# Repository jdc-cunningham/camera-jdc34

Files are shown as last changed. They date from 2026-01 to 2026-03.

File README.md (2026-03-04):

### JDC34 Camera

A custom camera body based on Raspberry Pi ecosystem

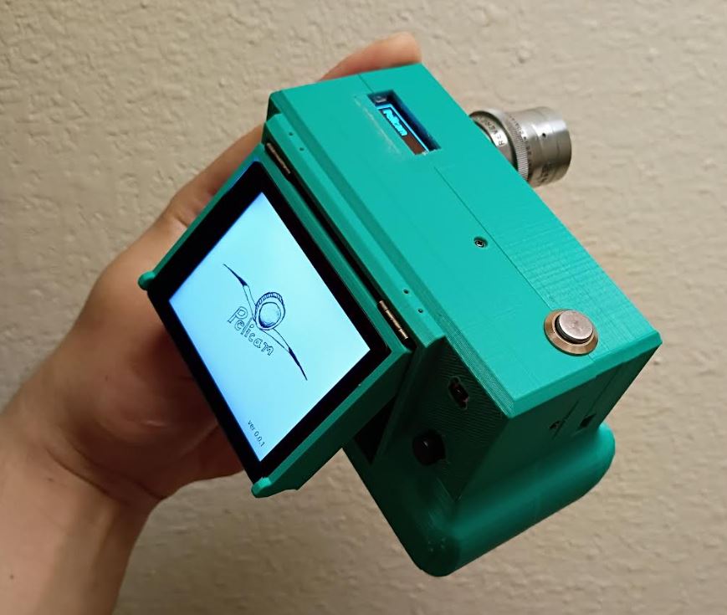
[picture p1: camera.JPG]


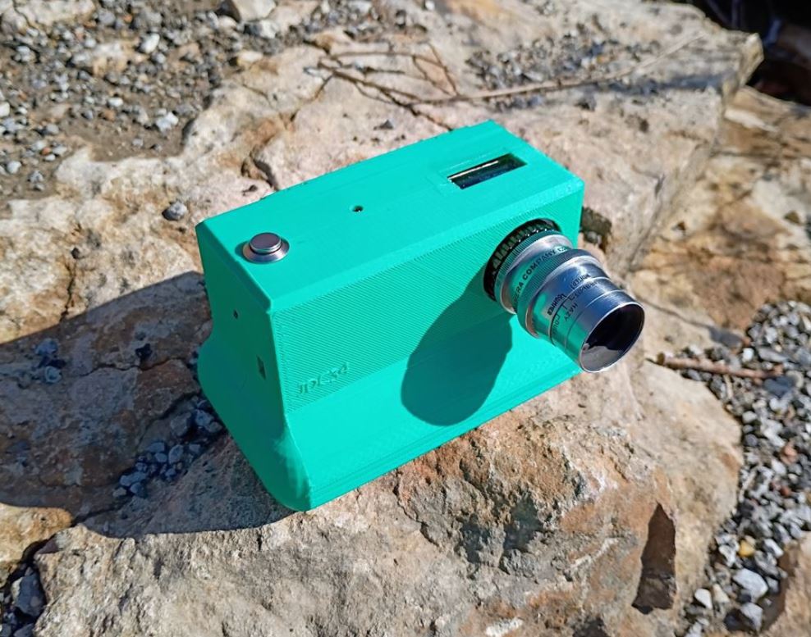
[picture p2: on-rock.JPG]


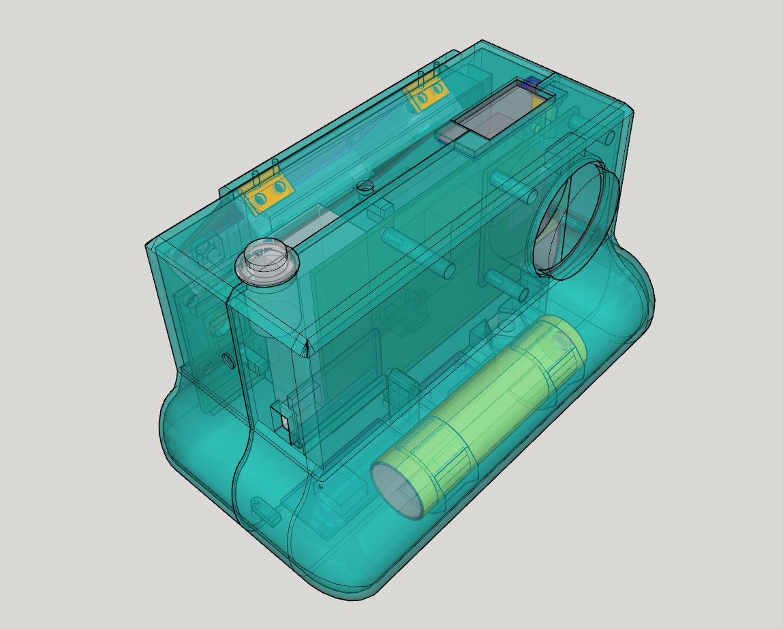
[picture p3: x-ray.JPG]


#### Features

- 2.8" 480x640 DSI waveshare touchscreen display
- 0.91" OLED
- 10-axis IMU
- 7 physical button interface
- full sized Raspberry Pi 4B
- powered by single 18650 cell

### Unit cost: $231.00

See the [parts list](./hardware/PARTS_LIST.md)

Note: you can reduce price in some areas eg. using a smaller SD card

Lens not included in cost

### Software

This uses [Pelicam](https://github.com/jdc-cunningham/pelicam) which is in development. The original software is [here](https://github.com/jdc-cunningham/modular-pi-cam/tree/master/cameras/pi-zero/large-display/software). But that was written for SPI displays.

### Media

For development videos and sample photos see my hardware YouTube channel [Vanta Wing](https://www.youtube.com/watch?v=lcudzqBnKbo&list=PL60azPuS5CZjkKGVGffiGK8XfBCXdif9R)

### About the name
The name is my name but also it's 3 c's (including the word camera) and the camera number. Yeah I do have other camera bodies I want to design and make. One would be based on the ESP32 ecosystem, means lower resolution but yeah.

I haven't thought of an actual name for this camera so... I figure I'd just use numbers.

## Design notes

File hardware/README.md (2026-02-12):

### Hardware

See the [parts list](./PARTS_LIST.md) for itemized breakdown of parts and cost.

#### Please note:

The tiny OLED on top eg. 0.91" OLED requires a 3A DC-DC boost converter to work (along with the rest of the system).

The cheap 2A DC-DC boost converter will not cut it (results in the 0.91" display being scrambled on boot).

Either don't use it, or use it and get a more expensive power supply like this one: (`$15` each vs. `$0.70` each eg. 2A)

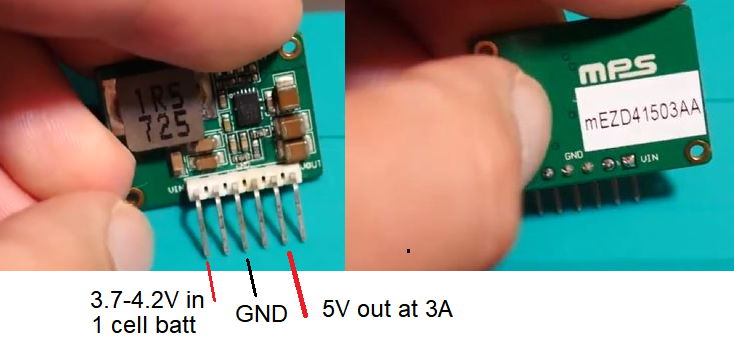
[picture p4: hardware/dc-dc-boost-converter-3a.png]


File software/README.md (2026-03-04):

### Software

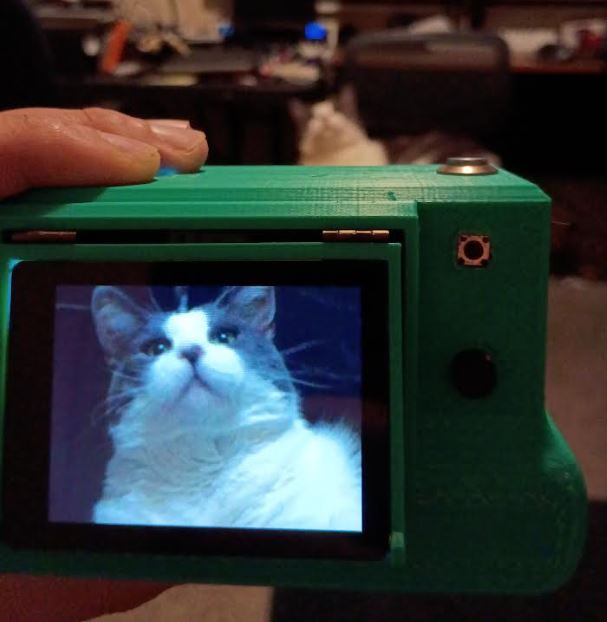
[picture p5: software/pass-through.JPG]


### Minimal software

See this [video](https://www.youtube.com/watch?v=SRtKM-NrlgQ) going over this code.

This code is crude, I put it together in a day so I could use this camera the following day.

Very basic camera software that features these abilities:

* button interfacing
* show live camera passthrough
* take a picture
* view the picture through list on touchscreen
* display text on OLED

#### Prerequisite

There is quite a bit of initial setup process on this [page](./fresh-os-install-steps.md).

I need to do that thoroughly/not in a rush.

After that you can do the following:

- Make a virtual env

In this software folder run `$python -m venv .jdc34-cam` then activate it

After that, run `$pip install -r requirements.txt`

- openbox

Do `$chmod +x` on openbox

- launch the window

`$sudo xinit ./openbox`

- running the menu on boot

I used systemd to do this. You can see this [page](./systemd.md) on setting up a systemd file.

### Pelicam

[Pelicam](https://github.com/jdc-cunningham/pelicam) is the full-featured software intended to drive different camera modules, display types and small or full-sized Raspberry Pis.

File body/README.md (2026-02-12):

### Disclaimer

Please note: I designed, printed and built this camera in 3 days.

The front shell needs some corrections, I'll remove this message once I have made the changes. In general this mesh is messed up, I did the modeling in SketchUp and it has problems with solids. Refer to the design flaws file.

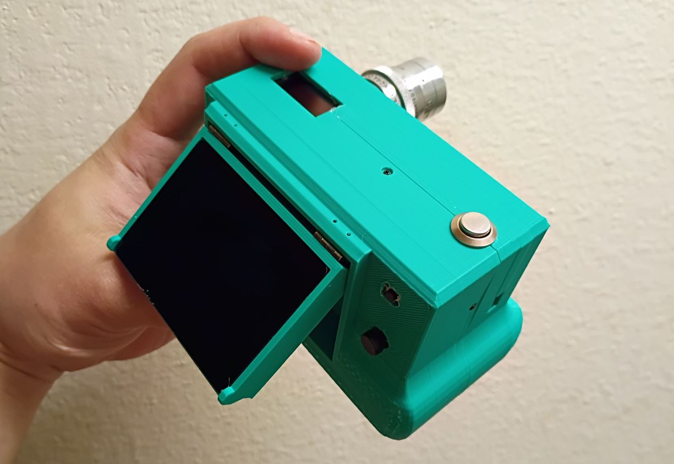
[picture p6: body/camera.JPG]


### Print times at 20% infill

- Display caddy - 2hrs
- Back shell - 11 hrs
- Front shell - 13.5 hrs

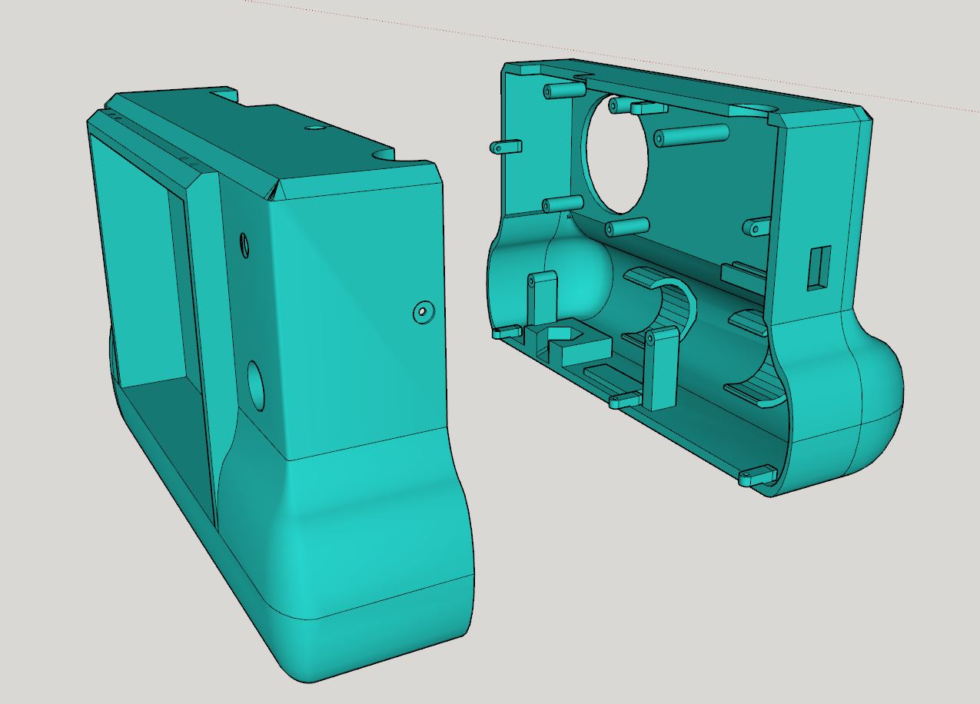
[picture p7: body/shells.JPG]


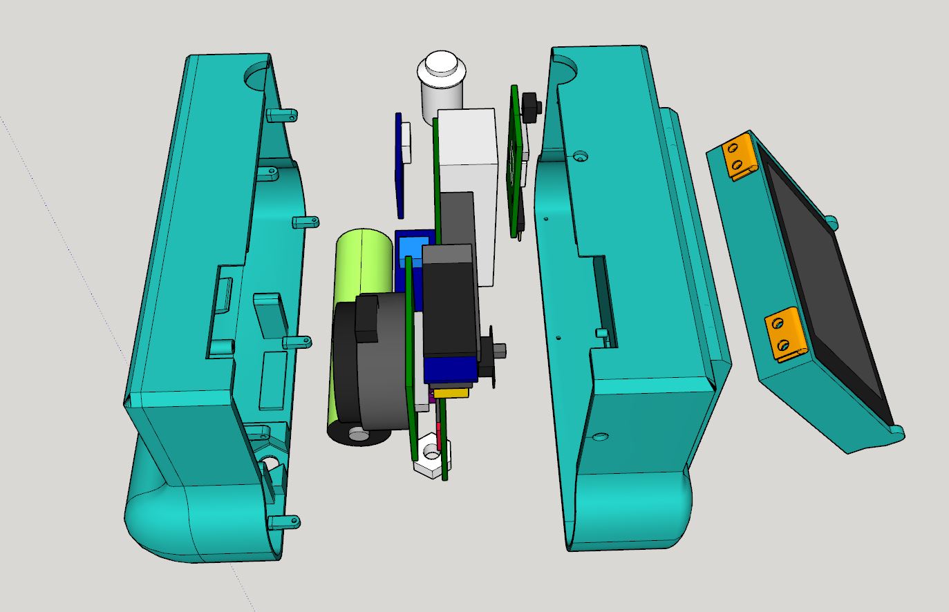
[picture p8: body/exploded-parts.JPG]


### Design flaws

I've written this on [another page](./design-flaws.md)

#### Note about the lens mount

I did not realize that the [flat plate](http://forums.raspberrypi.com/download/file.php?id=75978) part of the lens mount can be adjusted (flat screw) and then there is the CS adapter itself that can be moved. In this camera I designed the flat plate to be flush against the camera body. Ideally that would be able to rise below/above the front part of the camera, I need to adjust the design for that.

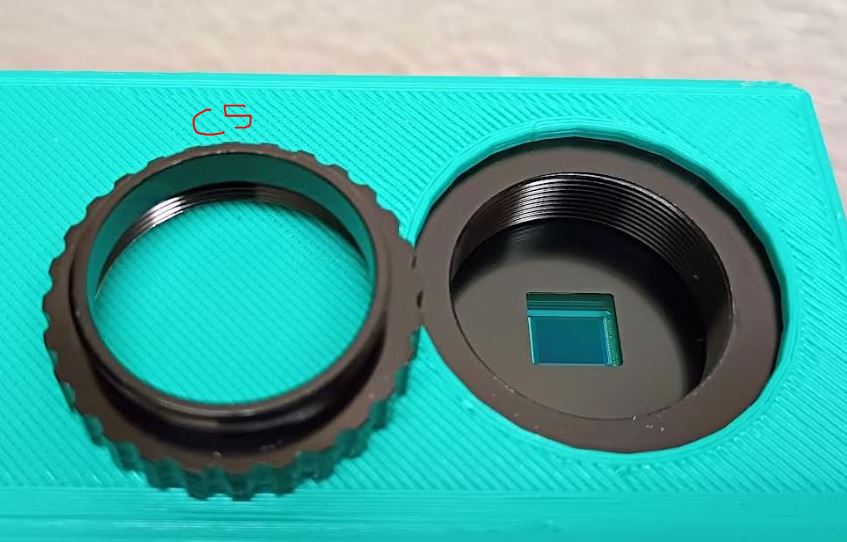
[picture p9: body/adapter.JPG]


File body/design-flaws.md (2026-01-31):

### General notes

The surface finish is from choice, if you print it the other way it takes a lot longer but you'll get a nice smooth finish vs. where support was detached.

The specific problems:

- HQ mount pegs are wrong, don't match, so I just hot-glued the HQ cam to the body which is not bad since you're going to attach
- the bottom-left mount for the RPi 4B is not actually attached when it prints which is weird
- the screw mounts that hold the two halves together are too small/frail, be careful, I snapped one of them on accident and had to print this A-shape thing to go around the broken screw mount
- the charger holder is bad, I need to make that be two ends and as L shape, no support in between that is hard to take out, the problem is the charger gets hot, hot enough to re-melt hot glue
- the back-button on the back shell, is not designed right, needs to be a square

While not intentional, it's tight to close the screen, since the hinge doesn't have any resistance, it just follows gravity. Currently the scringe hinge as is works well for pushing it in/keeping it closed.

I did fix the OLED cutout, it was too big for my taste, and I just printed a small wedge and superglued it on mine. But you can see if you print this as is you will get a usable body.

### External design flaws

- hinge gap and back button

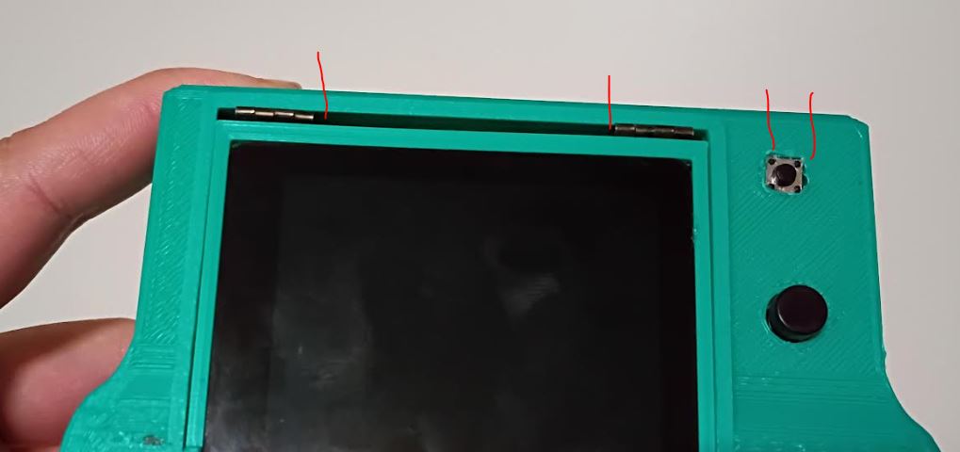
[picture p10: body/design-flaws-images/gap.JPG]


The back button I had designed the center black part to pop out just a little bit, while the outer part (tiny black dots) were underneath a thin piece of plastic, this was a mistake, as the smaller outer dots are almost are pretty tall... I ended up just having to take a soldering iron and roughly cutting out a square and hot-gluing it in place.

The hinges should have been pout out to the side more, I didn't realize how big of a gap that is in the middle, in that case you'd just drop the ceiling. The top of the LCD lid flips away so the ceiling can just be pulled straight down.

Although not shown here, the bottom of the display presses tightly into the body through compression not by design, it was lucky.

I would also put fixed/rotated slats/angles so the display can open at certain angles and not flop around like it does now based on gravity.

- OLED hole is too big (fixed in 3D model)

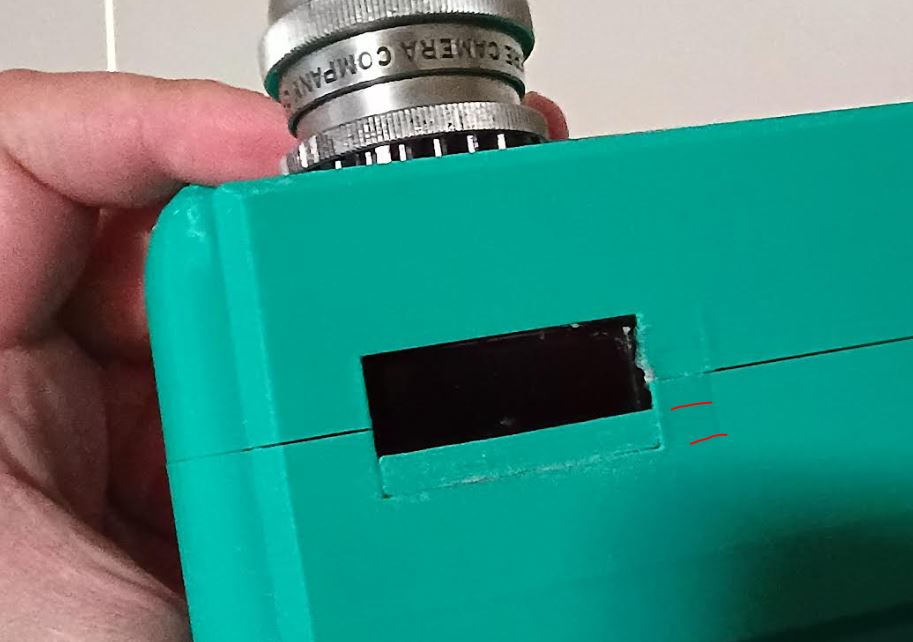
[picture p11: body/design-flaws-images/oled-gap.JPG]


You can see in red the size of the gap. The Pi 4B actually runs pretty warm so when I filled that in, I added a ramp shape so it can still let air out, since there aren't any directly-designed air flow holes.

### Internal design flaws

- charging board

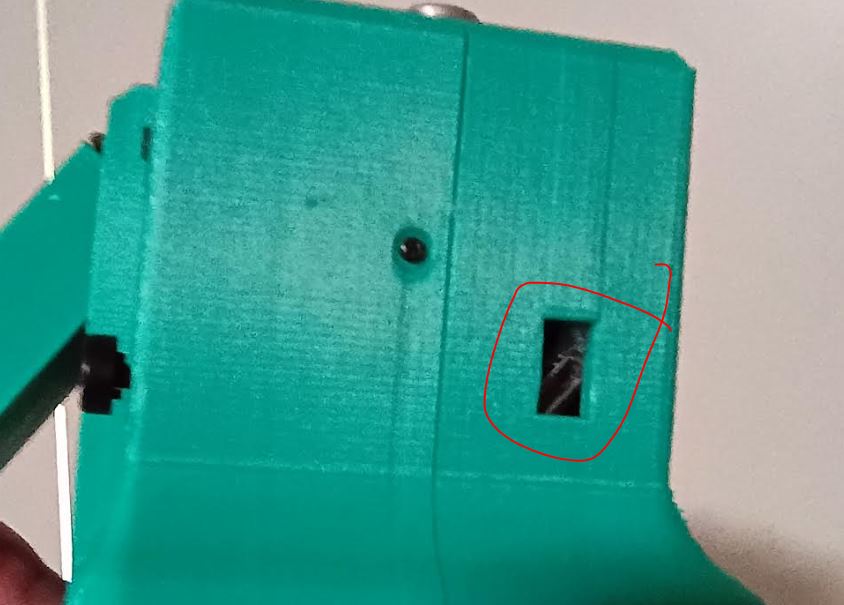
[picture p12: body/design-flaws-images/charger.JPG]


This is an external video but you can see the result I have. The problem is this board gets hot while the battery charges. So it will unmelt hotglue. I didn't design a good support for it internally.

- switch and screw holes

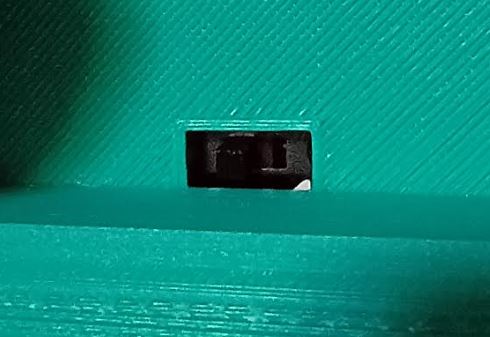
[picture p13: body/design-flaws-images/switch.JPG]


This is another external photo but inside, the screw mounts were too small, I ended up just hot-gluing the switch the body.

The other problem is it's not that easy to get access to the switch, I use the tip of my finger. I was aware of this while designing it but I was focused on making the switch hidden.

Not directly visible but side screw holes are also problematic. I have to make them thicker so they're not so easy to break.

No seam, because the shape is not normal and in some places thin, so I didn't design a seam. All the other cameras had a seam but they were simple rectangle edges.

- HQ cam screw mounts

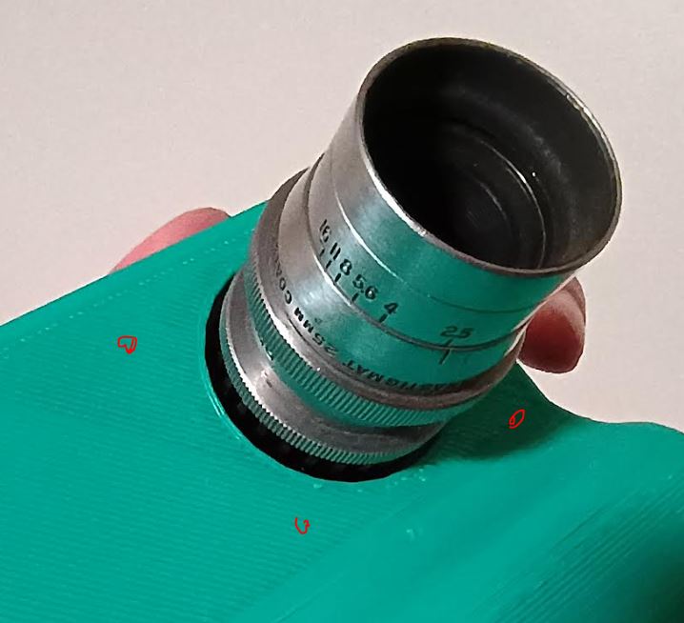
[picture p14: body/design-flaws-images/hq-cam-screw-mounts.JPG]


So I think what happened here is I used Arducam's IMX477 board measurements so the holes are off. If they do match then nvm but I believe I pulled a model I made around that board from the ML Hat Cam. Anyway the screw mounts didn't line up and I also ended up hot-gluing the sensor to the camera body. Which is not a bad thing considering how many random lenses/big lenses I attach to this camera.

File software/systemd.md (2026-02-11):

### Create a service

You can name the service whatever you want.

```
$sudo nano /etc/systemd/system/jdc34-cam.service
$sudo systemctl enable jdc34-cam.service
$sudo systemctl daemon-reload
$sudo systemctl restart jdc34-cam.service
```

#### jdc34-cam.service contents

```
[Unit]
Description=Start JDC34 Camera Software
After=multi-user.target

[Service]
Type=idle
WorkingDirectory=/home/pi/camera-jdc34/software
User=root
ExecStart=xinit ./openbox
Restart=always

[Install]
WantedBy=multi-user.target
```

Openbox will launch a window which will run main.py which runs OpenCV

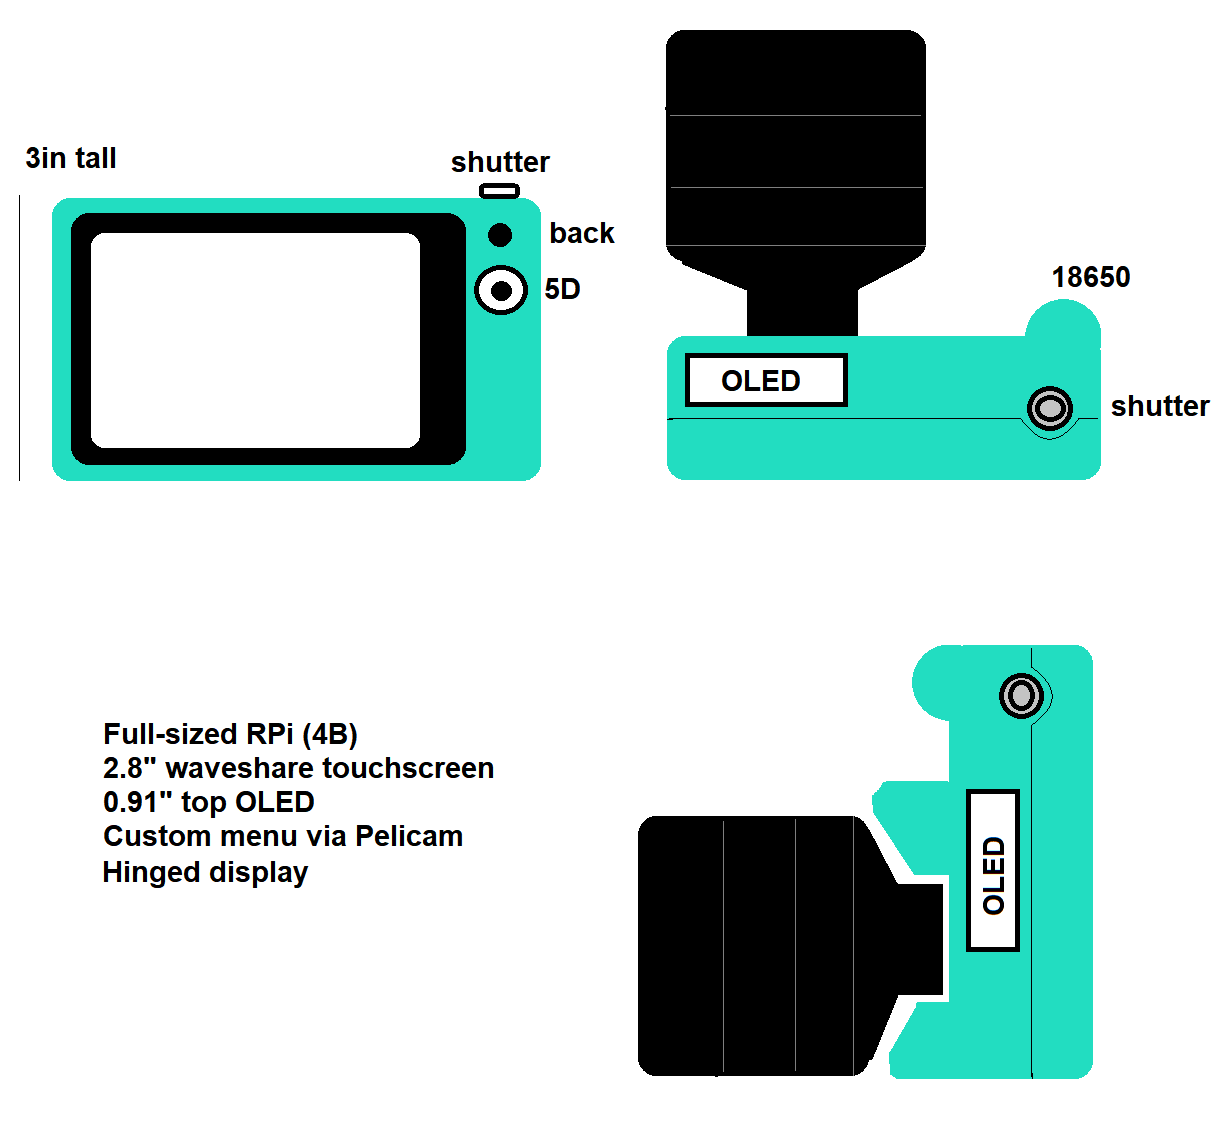
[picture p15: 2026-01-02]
init-design.png

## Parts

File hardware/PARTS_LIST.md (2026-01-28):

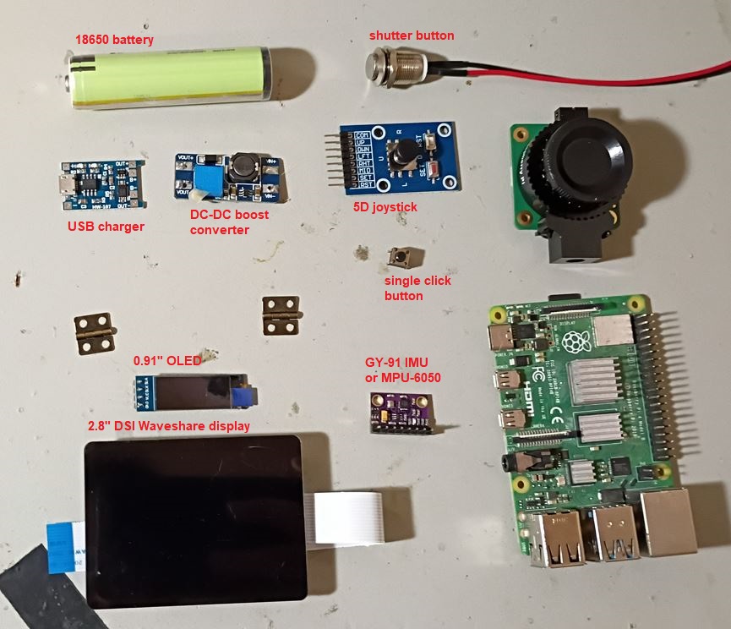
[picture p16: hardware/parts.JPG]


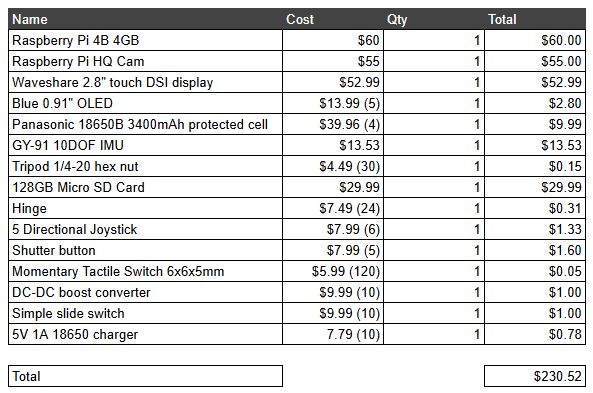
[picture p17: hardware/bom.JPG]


Amazon Affiliate Links

0.91" OLED https://amzn.to/49jh50v

2.8" Waveshare Touchscreen DSI Display https://amzn.to/49jh50v

DC-DC boost converter https://amzn.to/49jh50v

GY-91 10DOF IMU https://amzn.to/49jh50v

5D joystick https://amzn.to/3NcuRKW

1S BMS https://amzn.to/3NcuRKW

USB Li-Ion charger https://amzn.to/3NcuRKW

single button https://amzn.to/44TAjIT

shutter button https://amzn.to/44TAjIT

pack of assorted resistors https://amzn.to/453sS1S

Not pictured is a 10K resistor needed for the buttons

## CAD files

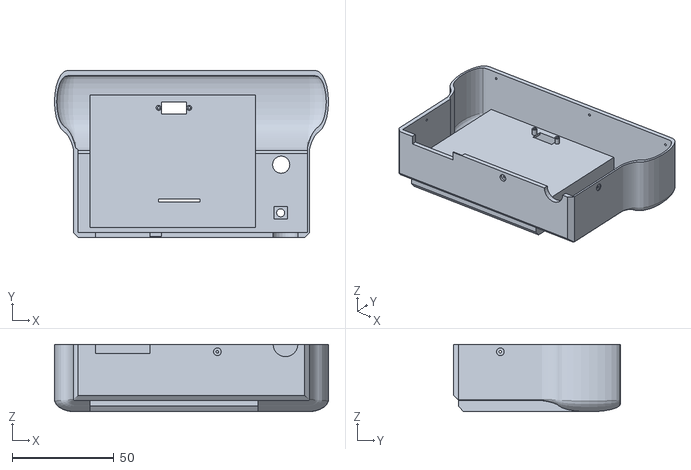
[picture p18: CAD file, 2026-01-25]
body/3d-models/stls/back-half.stl
134.7 x 82.1 x 33.2

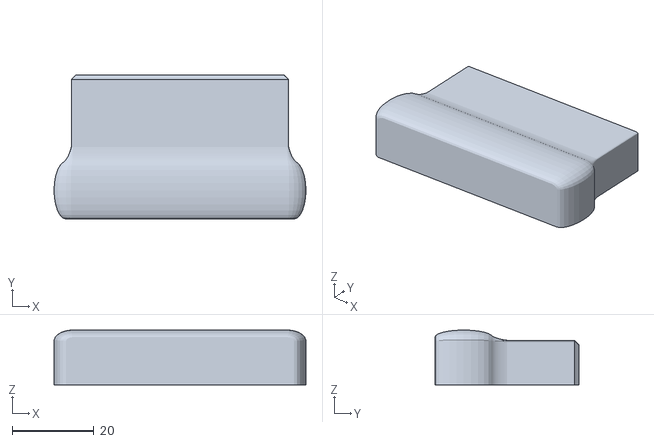
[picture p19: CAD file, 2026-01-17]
body/3d-models/test-prints/test-print-shell-back-scaled.stl
61.5 x 35.2 x 13.4

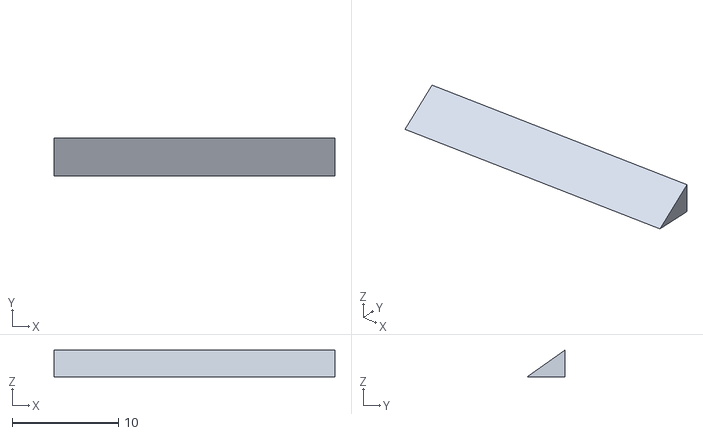
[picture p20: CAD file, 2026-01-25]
body/3d-models/stls/corrective-piece-oled.stl
26.5 x 3.59 x 2.54

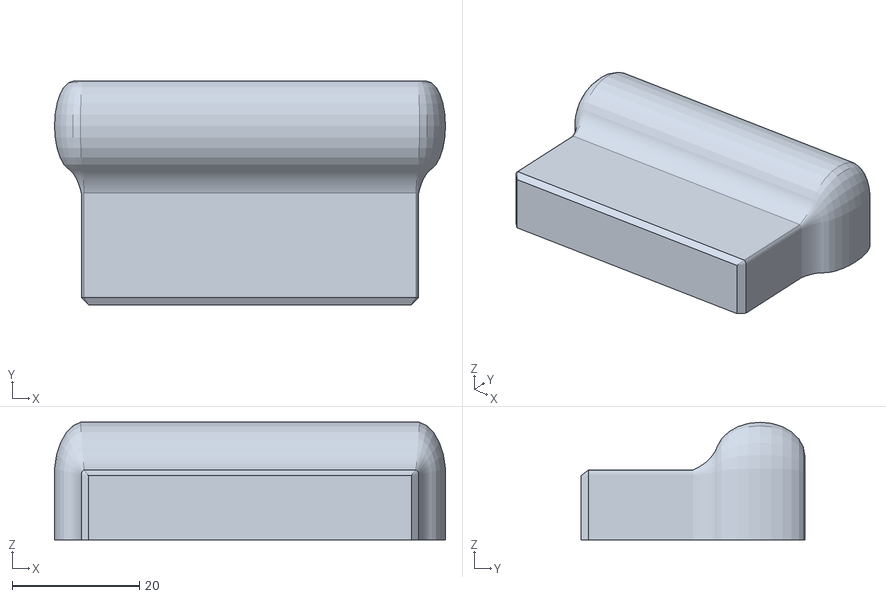
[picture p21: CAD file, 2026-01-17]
body/3d-models/test-prints/test-print-shell-front-half-scaled.stl
61.5 x 35.2 x 18.5

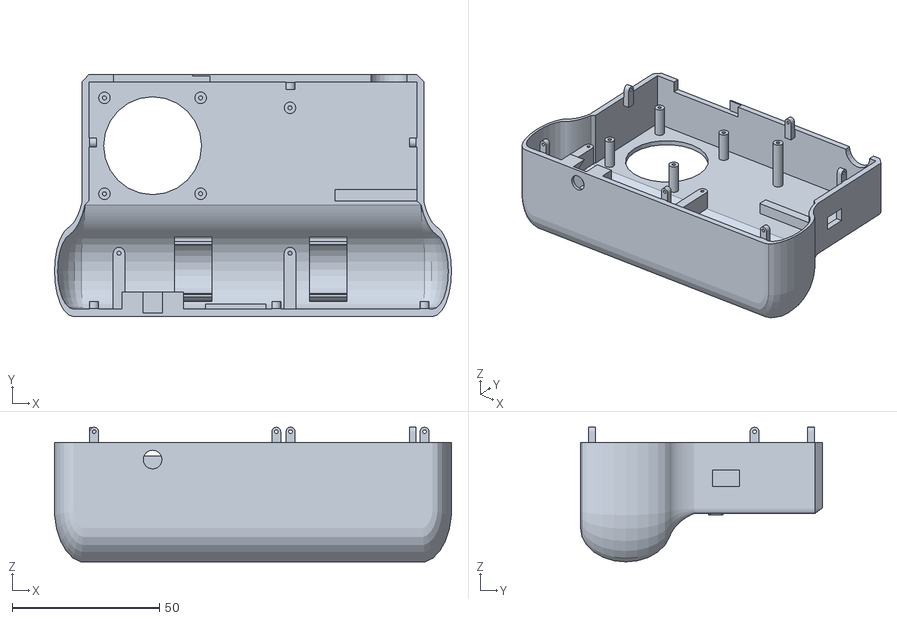
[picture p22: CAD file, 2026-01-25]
body/3d-models/stls/front-half.stl
134.7 x 82.1 x 45.7

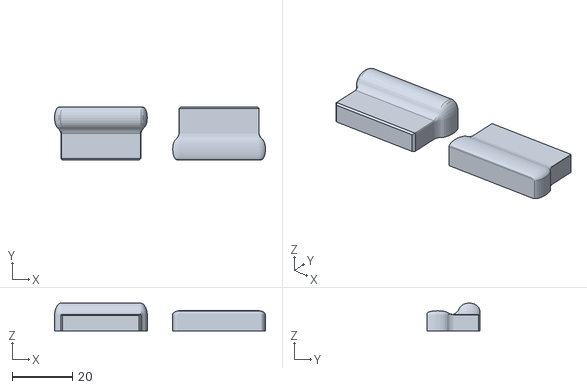
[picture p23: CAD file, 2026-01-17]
body/3d-models/test-prints/test-print-shell.stl
69.9 x 17.7 x 9.25

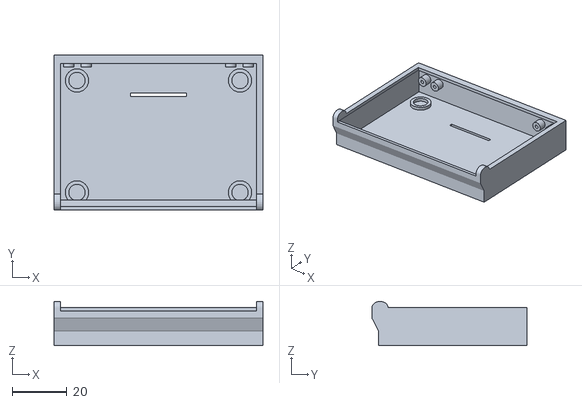
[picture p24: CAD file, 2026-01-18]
body/3d-models/stls/display-caddy.stl
76.3 x 56.7 x 16.2

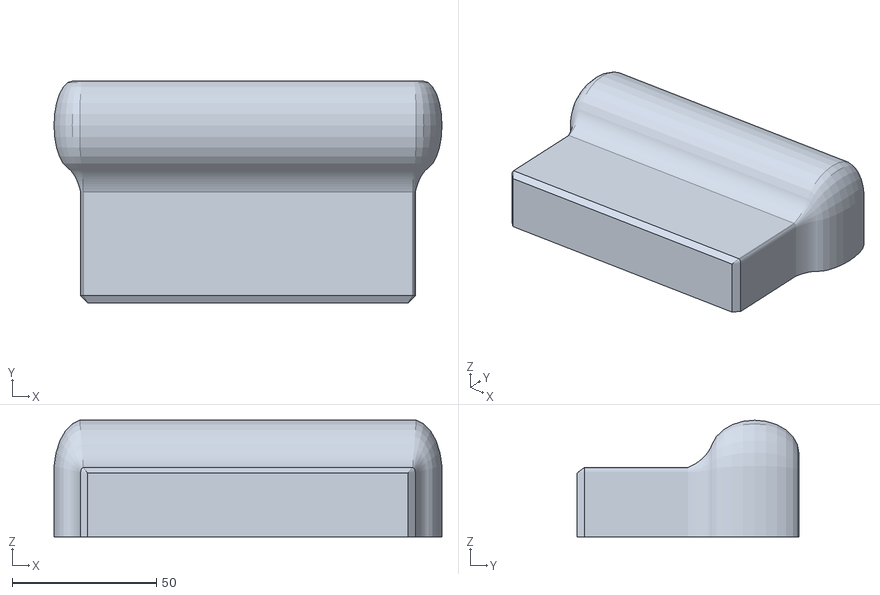
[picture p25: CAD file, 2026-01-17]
body/3d-models/test-prints/test-print-shell-front-half.stl
134.7 x 77.0 x 40.5

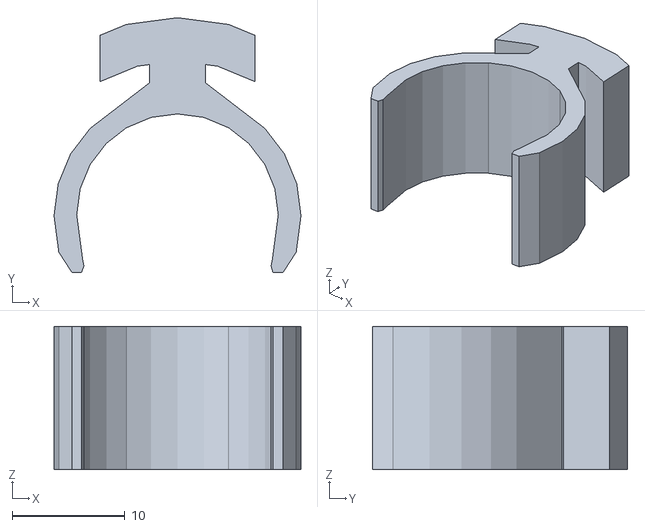
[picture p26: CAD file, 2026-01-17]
body/3d-models/test-prints/18650-battery-clip.stl
21.9 x 22.5 x 12.7

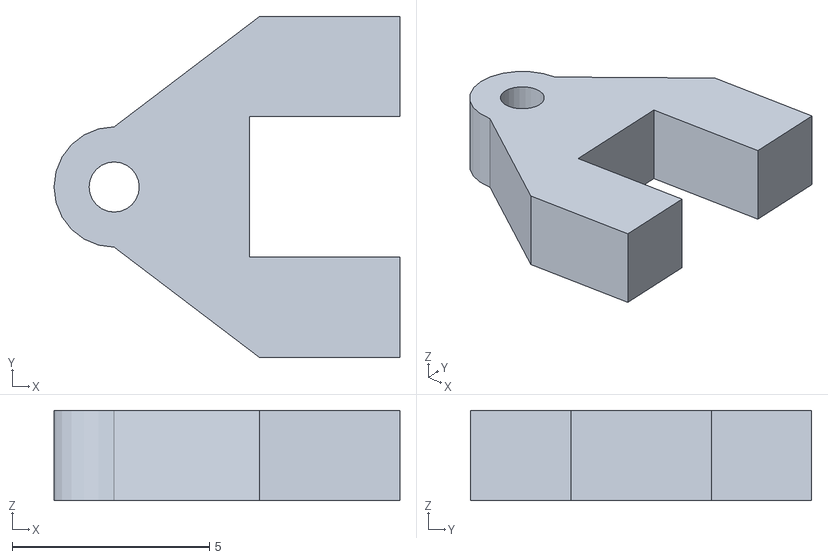
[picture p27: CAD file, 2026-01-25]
body/3d-models/stls/corrective-piece-screw.stl
8.76 x 8.64 x 2.29

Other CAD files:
body/3d-models/back-half-0.skp
body/3d-models/back-half.skp
body/3d-models/camera-assembly-0.skp
body/3d-models/camera-assembly.skp
body/3d-models/corrective-piece-oled.skp
body/3d-models/corrective-piece-screw.skp
body/3d-models/display-caddy.skp
body/3d-models/electronics-and-parts/0.91-inch-OLED-0.skp
body/3d-models/electronics-and-parts/0.91-inch-OLED.skp
body/3d-models/electronics-and-parts/18650-protected-cell.skp
body/3d-models/electronics-and-parts/2.8-inch-dsi-display.skp
body/3d-models/electronics-and-parts/5-d-joystick.skp
body/3d-models/electronics-and-parts/5v-1a-charger.skp
body/3d-models/electronics-and-parts/GY-91-IMU.skp
body/3d-models/electronics-and-parts/adafruit-speaker.skp
body/3d-models/electronics-and-parts/back-button.skp
body/3d-models/electronics-and-parts/dc-dc-boost-converter.skp
body/3d-models/electronics-and-parts/hinge.skp
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

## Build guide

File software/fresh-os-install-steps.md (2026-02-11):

### Steps to be able to run this software

Written for Raspberry Pi 4B, later will cover Pi Zero 2W

This is on Debian Trixie

- if relevant, do DT overlay for non-raspberry pi display eg. waveshare

- $sudo apt install python3-dev
- $sudo apt update
- $sudo apt upgrade

development

- add github ssh key
- set global git config
- $sudo apt install git

verify python installed by default (yes python 3)

screen

- $sudo nano /boot/firmware/config.txt
- write the `dtoverlay` per display

peripherals

- enable i2c

reboot

GUI display

- $sudo apt install openbox obconf
- $sudo apt install xinit
- $sudo apt install x11-xserver-utils
- $sudo apt install xterm
- $sudo apt install menu
- $sudo apt install xorg
- $sudo apt install unclutter
- $sudo apt install xinput

Test GUI

- make openbox file, put in:

```
#!/bin/sh

# rotate screen
xrandr -o left

# rotate touch
xinput set-prop 6 "Coordinate Transformation Matrix" 0 -1 1 1 0 0 0 0 1

# set python venv
. /home/pi/pelicam/bin/activate

# hide mouse cursor
unclutter -idle 0 -jitter 2 -root &

# start GUI
openbox --config-file ~/.config/openbox/rc.xml --startup /home/pi/menu-stream.py
```

need to have openbox set

run

- $sudo xinit ./openbox

follow up

`$sudo apt-get install build-essential libcap-dev`

for picamera2

`$python -m venv --system-site-packages .pelicam` (this did not help, not on bookworm, using Trixie)

for venv, to pull in picamera2 deps

install opencv

```
ERROR: pip's dependency resolver does not currently take into account all the packages that are installed. This behaviour is the source of the following dependency conflicts.
types-seaborn 0.13.2 requires matplotlib>=3.8; python_version >= "3.9", which is not installed.
types-seaborn 0.13.2 requires pandas-stubs, which is not installed.
```

sudo apt install -y python3-picamera2

chmod +x on main.py

sudo apt install python3-smbus

OLED code had to change RST pin from 27 to 7

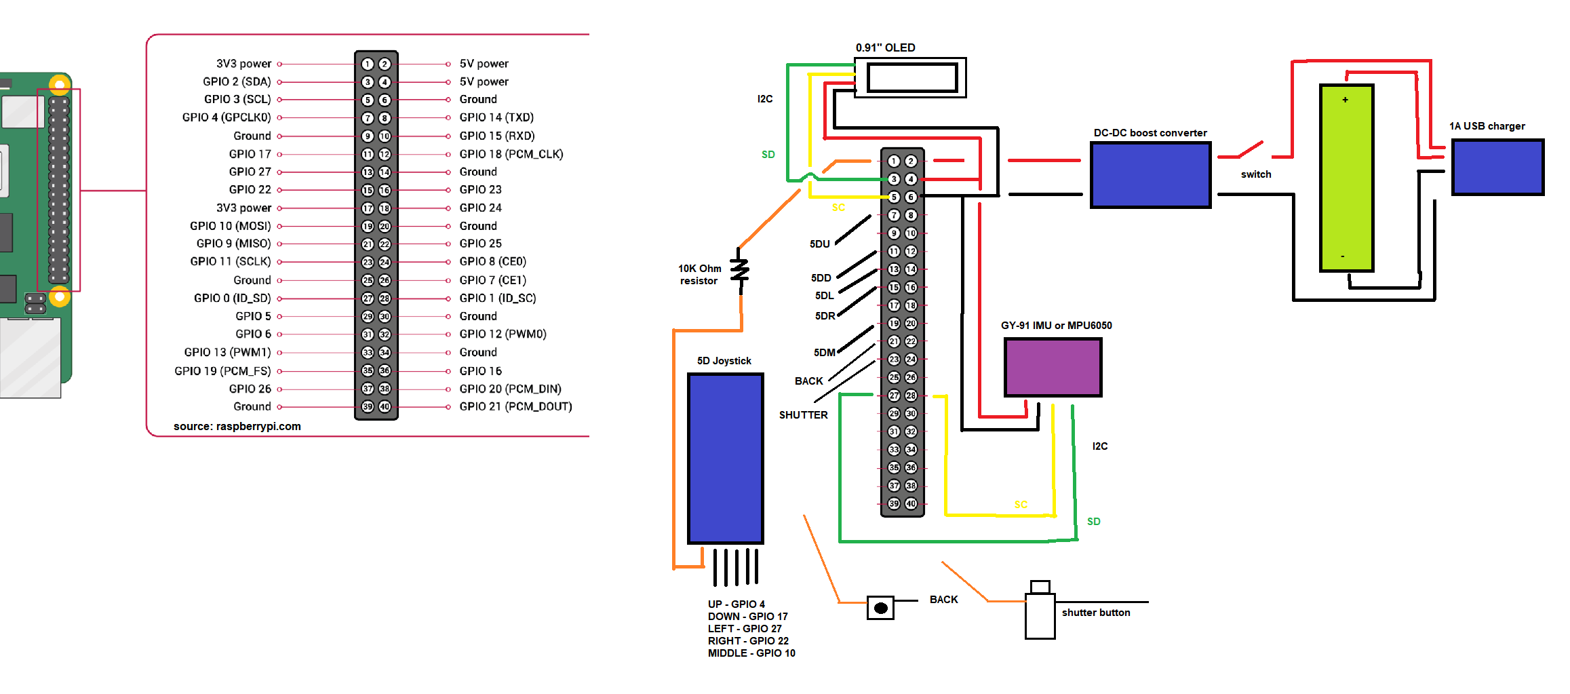
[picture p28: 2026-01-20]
hardware/electronics-wiring-diagram.png

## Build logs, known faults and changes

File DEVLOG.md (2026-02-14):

Tasks:

- [x] hardware
  - [x] interface with waveshare 2.8" display (DSI no pins)
    - [x] get display working
    - [x] figure out how to display a dynamic image-based menu with no OS GUI
      - decided to use OpenCV stream
    - [x] get coordinate click
  - [x] interface with OLED (get pins)
  - [x] interface with 5D make sure center click works (get pins)
  - [x] interface with IMU (get pins)

- [ ] modeling
  - [x] model the individual components to design the shell - some of these are already modeled
    - [x] Pi 4 model B
    - [x] DSI display
    - [x] 0.91" OLED
    - [x] GY-91 IMU
    - [x] RPi HQ cam
    - [x] 18650
    - [x] charger
    - [x] DC-DC boost converter
    - [x] back button
    - [x] 5D joystick
    - [x] shutter button
    - [x] hinge
  - [x] design the body
  - [x] test print for fit
  - [x] print entire body
  - [x] assemble
  - [x] finish wiring diagram

- [ ] software
  - see [pelicam repo](https://github.com/jdc-cunningham/pelicam)

### 02/14/2026

10:45 AM

I'm going to improve the basic software, namely:

- [ ] add the pan-zoom feature
- [ ] fix the view photo feature

The click coordinates are off and the photos seem to be "cached"

For zooming what you're doing is taking a larger picture and showing a part of it

So this display's resolution is 640x480

If we do 2x zoom then it's 1280x960

Full res is 4056xc3040 so that's quite a bit

You could probably do 4x

2560x1920

The other thing to address is I want the zoom to be touch-based, it should be click/5D pad based as well but not now, on Pelicam yeah

10:49 AM

I need to pull this repo down on the camera and switch software folders

11:14 AM

Alright for some reason I can't get openbox to find the venv path evne though it exists

So I'm just gonna develop this in that basic-software pelicam branch then move the code over here later

I have like 3 hrs to get this done which should be plenty if I don't run into dumb problems like this

### 02/11/2026

9:07 PM

Sunday looks like it'll be a good day

I'm gonna get a necklace camera so I can do photography POV videos

I'll update this code the minimal software namely:

- [ ] fix coordinate tapping (open right image)
- [ ] make sure new images open (weird issue like caching)
- [ ] add manual focus by tapping on the screen/panning by tapping left/right/top/bottom

That should help with better pictures, it will still be automatic though as I need to have a more complicated menu to hold stuff like ISO, shutter speed, white balance, exposure, etc...

I'll take the Rivere Scienar 24mm too this lens seems to be really good

What's bad is since the RPi HQ cam is hot glued to my camera's body, I can't adjust it per lens

I'm unscrewing the lens to focus the lens and I think the minor movement of taking a picture can unfocus the scene, but I guess go higher up in f-stop

I was surprised by the Canon 15-75mm TV Zoom lens's depth of field

Maybe even with this crop factor you can still have a nice depth of field blur

### 02/06/2026

5:37 PM

Sunday will be a nice day so I want to take this camera out. Means I gotta write basic code and I'll put it here since it's not Pelicam.

I'll write the code tomorrow when I wake up, I'm pretty tired.

6:10 PM

I'm mentally drained right now so just gonna think/plan out what to do tomorrow.

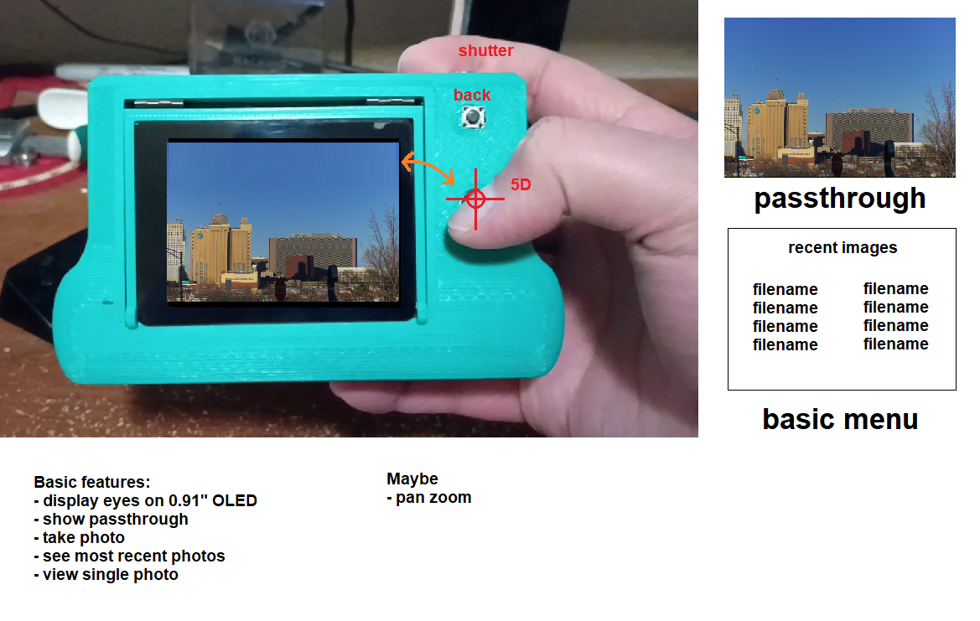
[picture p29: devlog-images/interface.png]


---

### 01/21/2026

8:46 PM

The Pi 4B can get warm, I should have designed in vents, it has holes so it's not like heat absolutely can't escape but yeah

---

### 01/20/2026

I got it fully assembled and wired today, verified all the buttons, OLED and IMU are connected.

Next is programming the software (Pelicam)

---

### 01/18/2026

10:40 AM

Back on, time to lock in gang gang

Gotta finish the display design, finish making screw holes and then do more test printing before printing the entire bodies

Then to wiring/assembling but each half of the camera takes like 8hrs to print so I may have to assemble tomorrow

11:35 AM

Alright I'm printing the display caddy full size, takes 2 hrs

Continuing on to adding screw holes for the other parts of the camera, what sucks is I have these tiny screws and I dumped the container (multiple sizes) so they're all just mixed together.

I make these cameras open source/all the design files and what not but it's so much work to make them... it's like who wants to do that.

12:48 PM

Man... I'm losing drive, it's so much work... I'm almost there

I had to make the body thicker to accomodate the RPi's ethernet/USB ports

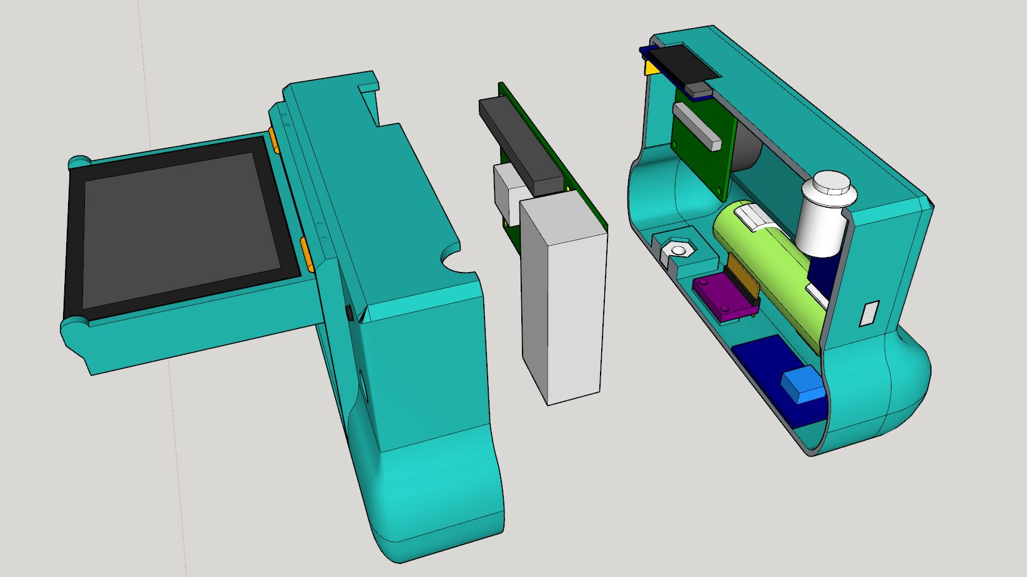
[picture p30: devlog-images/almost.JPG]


I'm not designing screw holes/mounts for the IMU or the DC-DC boost converter as those can be just glued down, same for the D-pad... I was going to but it's sandwiched against the display case, can just glue it.

So right now I have to design the screw mounts for the RPi HQ Cam (important due to being attached to huge lenses), the RPi itself (3 screws out of 4) and then the seam that joins the two halves together.

After that I'll have to clean up the body/check it's a mesh and then I scan start printing them.

I'll probably adjust the USB charger's position it's kind of in a weird spot, something to consider is it gets hot.

2:41 PM

Alright I'm about to print the back half.

If I print it edge down, it takes 14 hrs vs. the other way 10 hrs... so I'll sacrifice the nice smooth finish on the back for the speed to print

The edges being perfect will be nice

4:15 PM

Had a problem with the front shell not printing correctly, thankfully I was able to save it

5:31 PM

Just printing now

6:34 PM

Had to confirm the "daughter board" will fit and it does thankfully, though I have to cut the prototype solder board

Cool exploded view

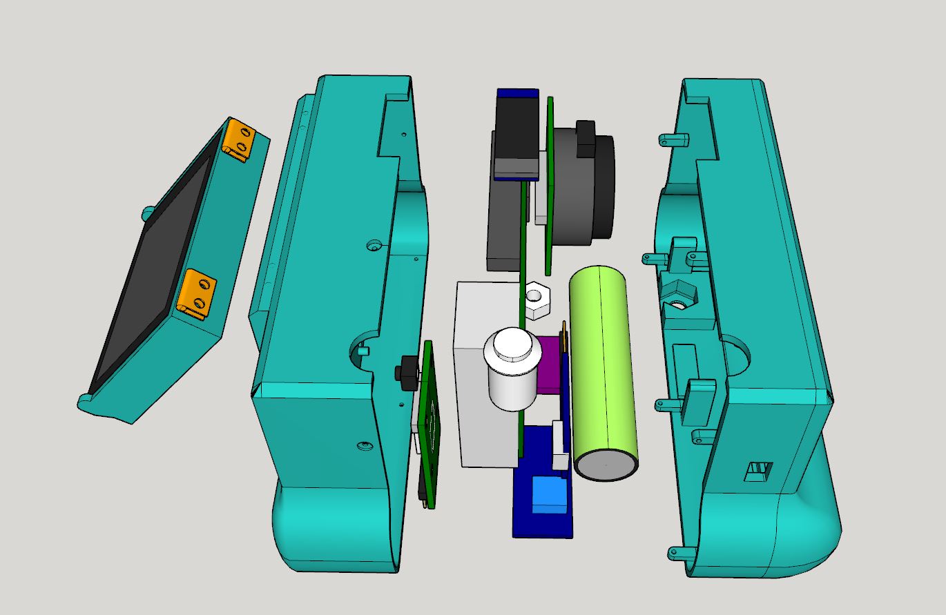
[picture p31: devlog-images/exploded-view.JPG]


5:25 PM

I'm back from doing some photography, the part is printed, there are errors

- [ ] HQ camera mounting is off, too thin
- [ ] RPi mount is not fully attached
- [ ] screw holders are thin in geneneral
- [ ] charger holder needs work
- [ ] hinge needs more room
- [ ] OLED hole is too big

I need to get that wiring diagram together so I can assemble it.

10:54 PM

Assembled as of now, waiting for battery to charge.

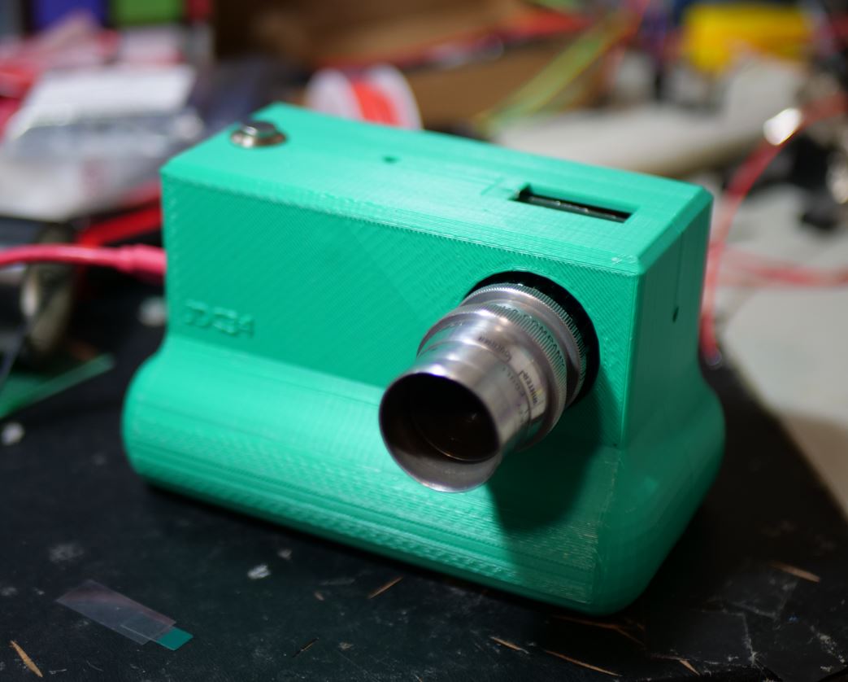
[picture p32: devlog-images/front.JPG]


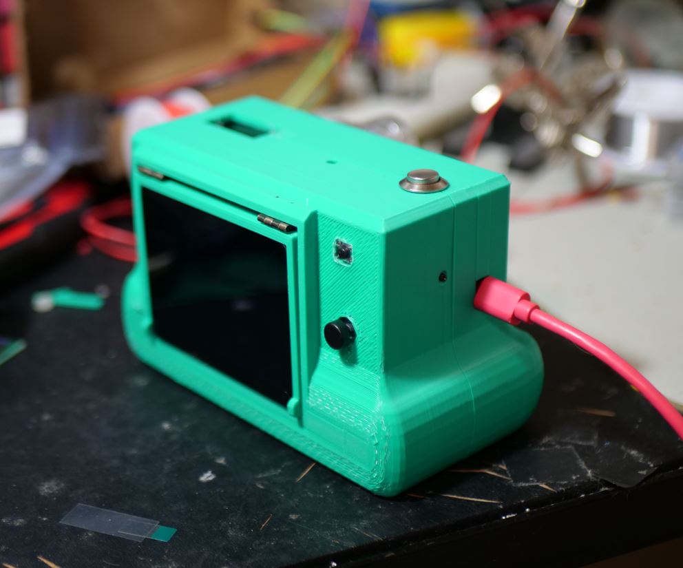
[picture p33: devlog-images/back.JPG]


---

### 01/17/2026

10:35 AM

Alright time to get in the zone autozone

Gonna finish the modeling then do test prints to make sure the screws and slots fit then do the entire body which each half takes idk 7-9 hrs

11:03 AM

Doing first print in a while, testing the fit of the 18650 battery clip, there's a term for it regarding flexing parts

It's not conformation or something but yeah

1:25 PM

I've been making progress

I don't really like this design but I need to get a better program than SketchUp and learn how to design rounded surfaces

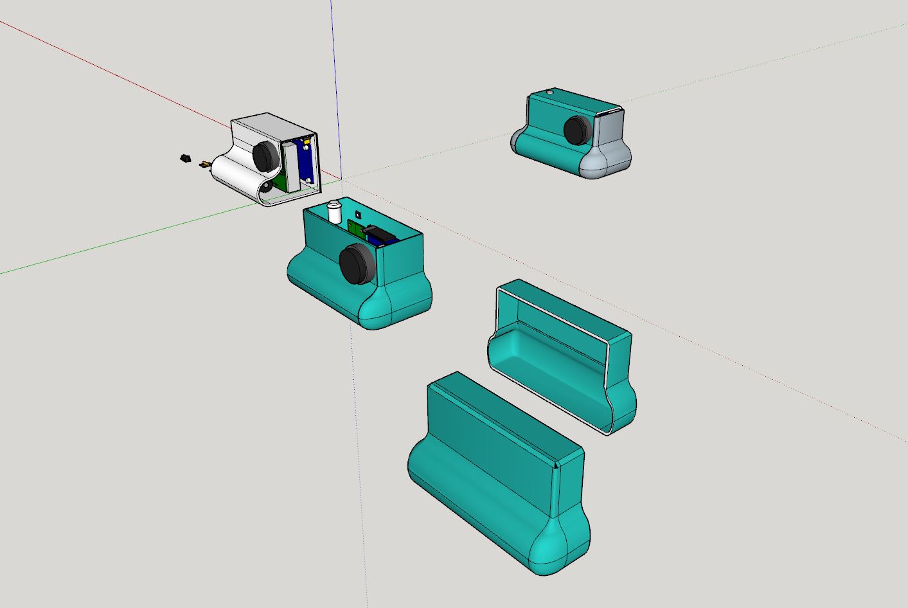
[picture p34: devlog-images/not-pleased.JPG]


At this point I'm still designing where I have to fix the broken mesh (not 3D not 3D printable) and then cut out the screw holes/mounts and what not. The back LCD is interesting since it intersects with the rounded bit.

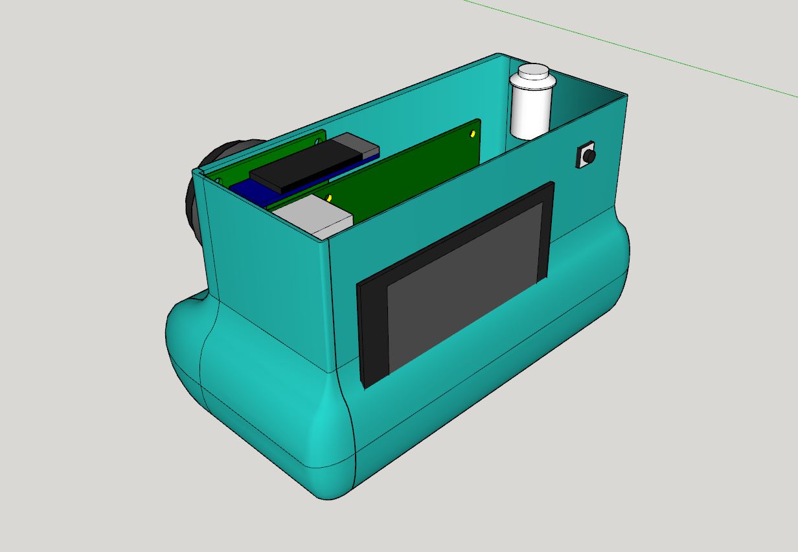
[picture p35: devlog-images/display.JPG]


Also not liking the top, since the edges are irregular, I'm not able to make a round shape and follow-along, trace the top edge, that's just a sharp angle.

3:21 PM

Back from a lunch break/shopping (alky)

Doing a test print under half scale.

5:24 PM

This is taking a while damn, still designing, decided the display will stick out past the body

7:21 PM

It's so ugly 😭

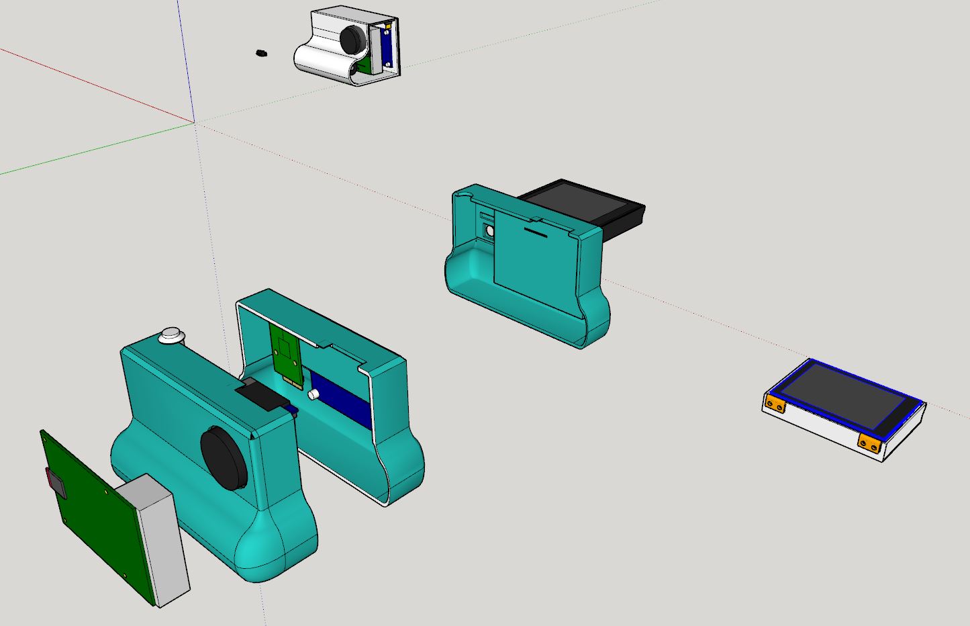
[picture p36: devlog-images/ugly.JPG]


That's what I should call it, ugly green camera

I did do the small 3D print, unfortunately the back part failed but I can already see... idk... it's like my car, if I look at it at the right angle it looks cool even though it's a hatchback.

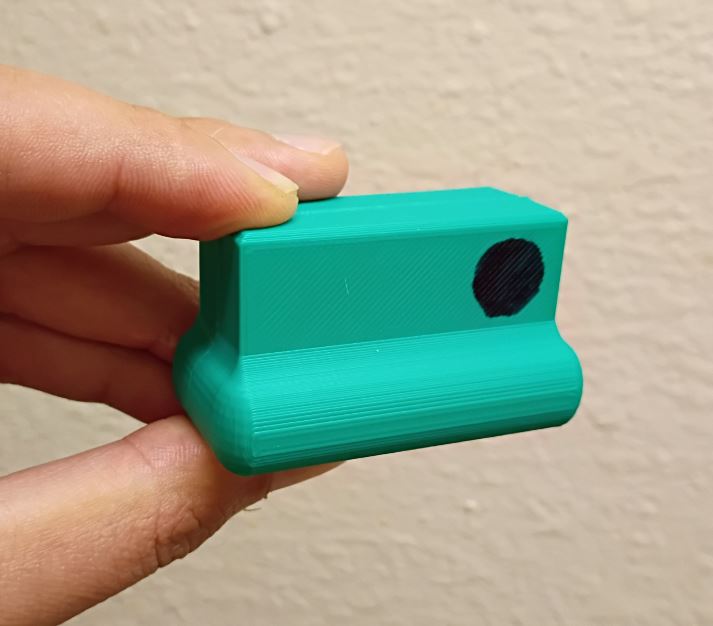
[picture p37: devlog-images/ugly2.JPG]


I did make good progress today, I'm almost there where I can print the two body halves.

I'm still finishing up the 

7:29 PM

The back looks cool, detailed but the front is ass... nothing just a long rectangle

Maybe I'll add a shape on it

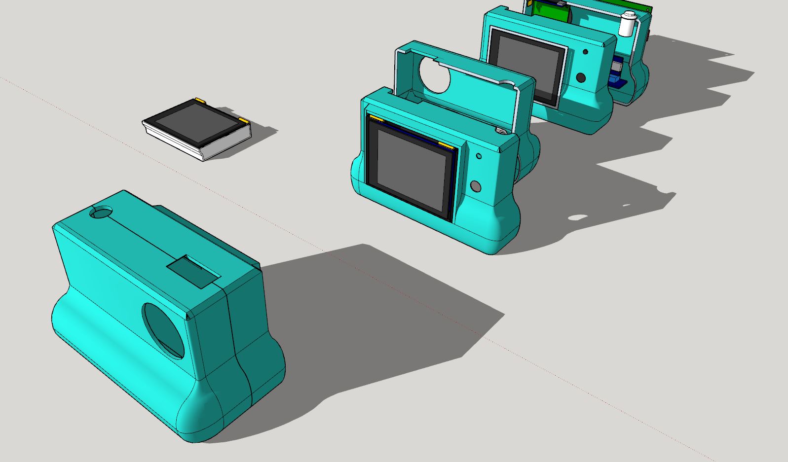
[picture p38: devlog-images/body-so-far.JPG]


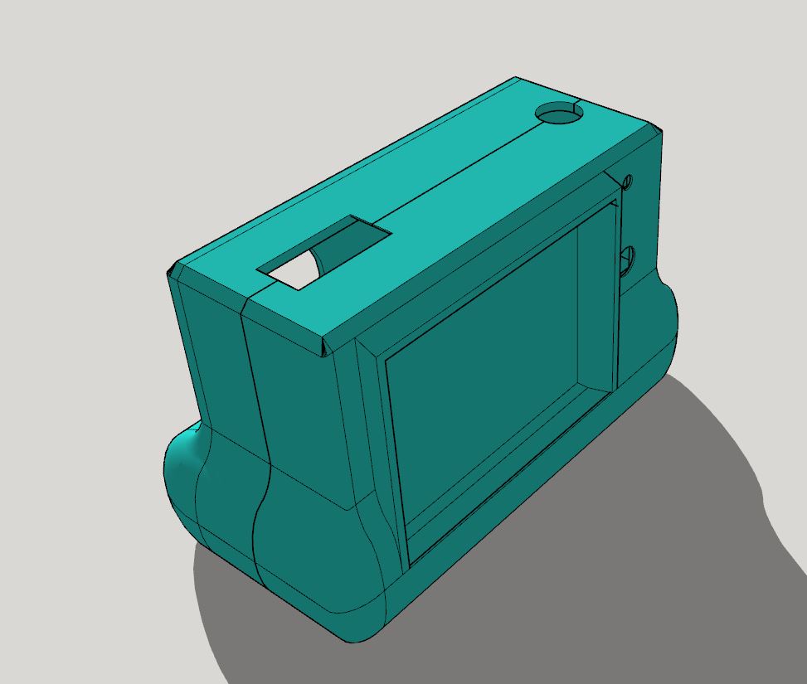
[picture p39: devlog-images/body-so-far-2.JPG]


7:34 PM

Well if I put the camera "serial" on the front it helps

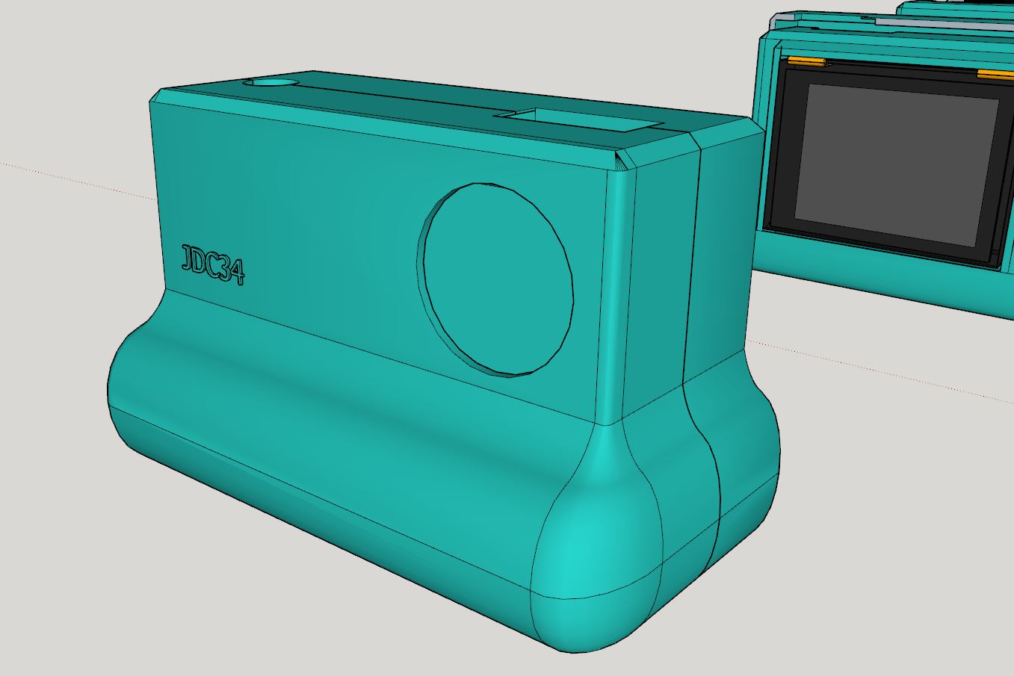
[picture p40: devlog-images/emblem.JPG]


---

### 01/16/2026

5:39 PM

I'm not doing any work today but I did decide I'm gonna skip the gym both Sat and Sun and focus on building this camera. It's a 3-day weekend so I should be able to do it. Also the weather is really bad the next couple days, it's like 20mph winds at 15 degrees F you know... that would suck to go out and try to take pictures.

I also ordered 5 more lenses... so that'll be more content. I have to finish and load up the menu on the camera but the 3D printing is loud so I want to do that during the day since I'm at an apt complex.

---

### 01/13/2026

6:27 PM

I'm going to switch gears from the menu/software work and do the modeling of the body.

Because it takes a long time to print so I figure if I can get ready to print over the weekend then I can do menu work while stuff prints.

I would really like to assemble this new camera too.

So time to start modeling, I'll record the whole process for that timelapse footage.

6:41 PM

I imported parts I had designed for other projects so that saves time

6:47 PM

I did buy a bunch of 1/4-20 hex nuts but since the raspberry pi camera comes with a tripod mount, might as well use it

6:50 PM

Alright gonna do some modeling

7:50 PM

Nice I only have two things left to model

8:06 PM

Alright all the parts going into the body have been modeled

8:17 PM

Here are all the parts imported into one SketchUp file which the body will be created in.

I did decide I'm not going to expose the Raspberry Pi's ports because it's supposed to be a camera and you can wirelessly talk to it/export the photos.

It kind of takes away from the camera design too when you see "oh it's obviously a raspberry pi in a box"

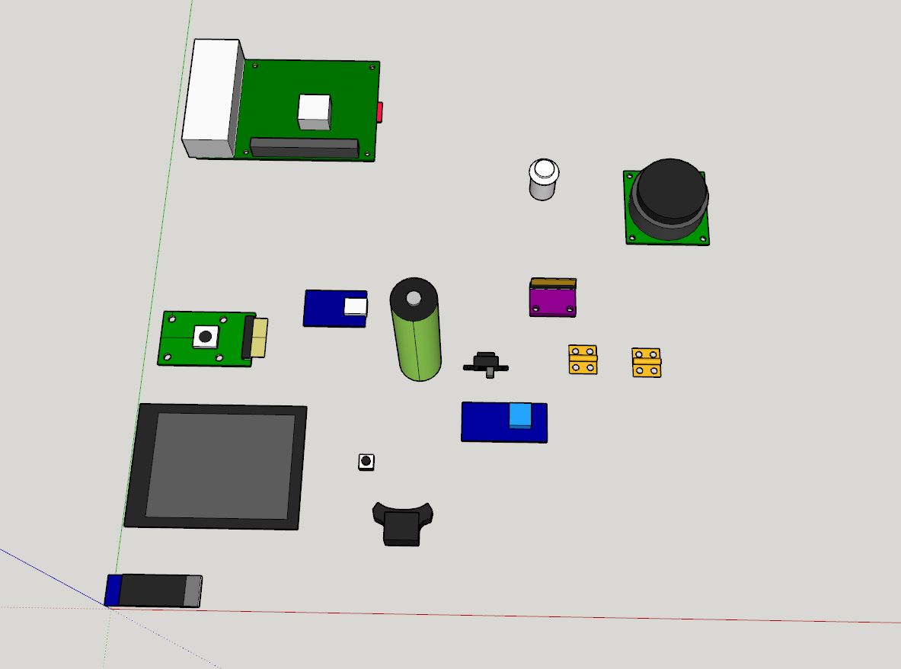
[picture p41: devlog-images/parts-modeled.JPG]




I'm mentally sold on this blue-green but I bought sea-foam green 3D printing filament so I should update the drawing to reflect that

Ehh we'll see it when it's real

8:46 PM

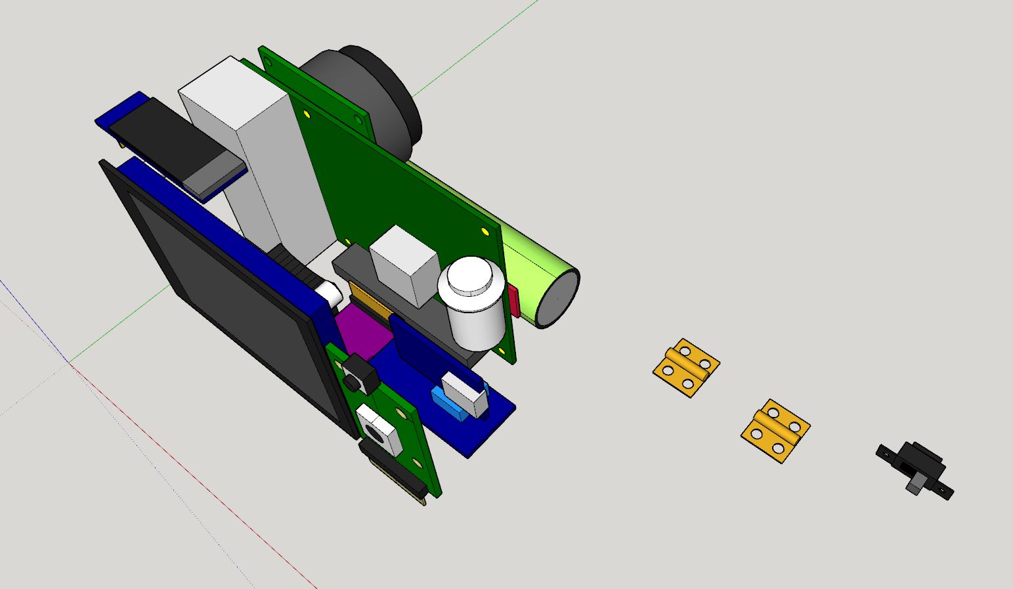
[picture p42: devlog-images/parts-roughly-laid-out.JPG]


I decided to put the switch under the display so it's hidden.

You can see the rough footprint above with all the parts arranged.

9:48 PM

I decided I'm going to add a speaker to this camera so it makes a shutter sound, that'll be more satisfying

10:10 PM

I actually thought of something funny, with the accelerometer on there you could whip the camera back and forth and it would start screaming like it was a living thing

---

### 01/12/2026

7:12 PM

I took the Vivitar 75-200mm lens out and it's huge/heavy.

It made me think about designing the body to just be a square/purely touch screen.

Because in that particular case, the lens itself would be attached to the tripod vs. the camera body

And then the display is just this thing you touch on the back of the lens... but you can just make more cameras

I'm realizing too that video looks great with this sensor but photography is ehh... definitely need to mess with the lighting more and stabilize for the case of telephoto

### 01/11/2026

5:55 PM

I had an idea... I can print the bodies smaller so they finish faster and I can get a feel for the ergonomics

I already saw another lens I want lol at least these lenses in general are like $40 each

### 01/10/2026

5:26 PM

I took the 25mm Revere-Scienar Anastigmat out and I got some really great shots of buildings in bright sunny days. The contrasting colors... and video looks even better.

But it made me think, I would consider designing two different camera bodies (one specifically for small cine-lenses the blue offset one) and then one for the C-mount to full frame adapters... that one would be more centered/bulky.

So I'm going for this design more where it looks quirky



### 01/04/2026

2:12 PM

Damn I feel like shit today, trying to reset my sleep pattern to go back to work tomorrow

That's one of my goals in life, not to have a fixed job so I can sleep/wake whenever my body wants to

The color palette thing arrives today, apparent your monitor needs to be calibrated too for it to work so idk

I'm working on the menu today, trying to get a working POC of the recursive folder walking

It's not just the nesting that determines the menu structure it's the icons too if they click and how far that icon goes, how many "pages" it has

I've been looking at vintage cine lenses, I'm imagining something where the lens is shiny silver and the body is beat up

Also the lens is tiny compared to the body

2:32 PM

Something like this, I've probably seen something that I'm referencing/thinking off but the lens is tiny and offset compared to the body.



Anyway I need to work on the menu/camera software

2:41 PM

Damn time flies, I saw that I made the pi zero hq cam 3 years ago

### 01/03/2026

6:25 PM

I'm still stuck in 2025 apparently

Well I went out with the modular pi cam and minolta again, this time the AWB tune was yellow than pink ugh

It doesn't look crisp either, hard to focus... I want to blame the small sensor but idk I also am not good at photography

And I'm using automatic settings which the new pelicam menu will be able to set

So last time I was trying to get click detection to work, after that I'm going to interface with the OLED and then I'll do the IMU and buttons... which I've done in the past.

After this I'll be working on the software, and modeling parts and designing the body. The seafoam-green PLA arrived today ha.

6:40 PM

Okay we've got clicking nice and the coordinate

moving onto the 0.91" OLED now

7:12 PM

Soldered the GY-91 10-axis IMU

Plugged in the OLED, I didn't buy a waveshare labeled one but this might be a waveshare clone

Looking at their docs

https://www.waveshare.com/wiki/0.91inch_OLED_Module

Using GPIO 2/3 for the OLED

7:18 PM

Trying BCM2835

Then doing the python commands

Installing python3-pil as is not in venv

Spidev not sure, I first just did it in venv went through then tried outside (deactivate) already installed

downloading test demo

7:28 PM

Ran example says "Only Device_I2C, Please revise config.py !!!"

Enabling I2C in raspi-config

Did not work, looking for the config.py file

Oh I mean I specifically setup SPI for this, probably wrong GPIO pins?

Installing i2c tools to scan

https://learn.adafruit.com/scanning-i2c-addresses/raspberry-pi

Okay I had my SDA/SCK pins backwards, I'm using i2c 1 for the OLED, I see it show up 3c

Setting I2C to 1 in config.py

7:52 PM

I'm doing the GY-91 now which I've used in the pi-zero-hq cam so I should be able to just pull that

11:36 PM

I'm working on a video right now.

At this point the hardware's all figured out. Now to design and 3D print/program the menu.

---

### 01/02/2026

3:06 PM

Oh man I'm feeling it now Mr. Krabs, the juice is flowing

I thought I was working today, dumb...

Today I'll interface with the Waveshare display, I ordered another RPi HQ Cam and Pi 4B from Adafruit but still waiting for that.

I'll use the other Pi 4 I have currently.

8:01 PM

Working on interfacing with the 2.8" waveshare DSI display, first try was a failure lol

Trying to add dtoverlay from this thread [https://forums.raspberrypi.com/viewtopic.php?t=366011]

`dtoverlay=vc4-kms-dsi-waveshare-panel,2_8_inch`to `/boot/firmware/config.txt`

8:10 PM

OMG it's so beautiful!

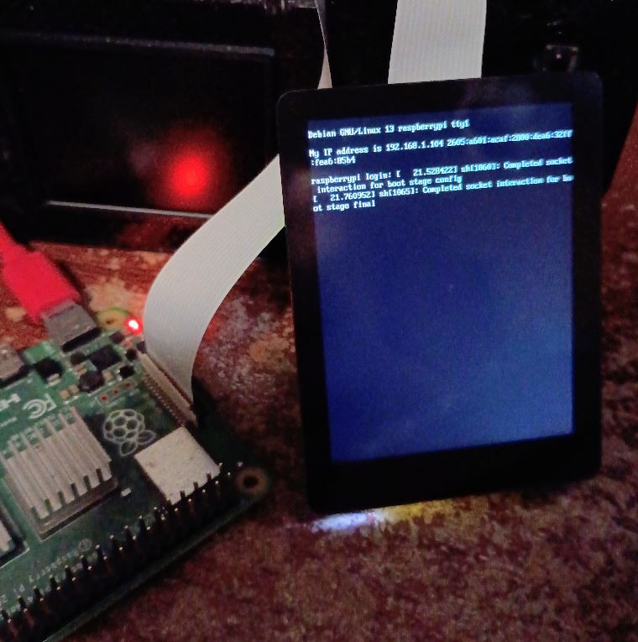
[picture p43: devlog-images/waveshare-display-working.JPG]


The DSI cable is nice, that means it doesn't use any GPIO pins

Wiki has some info who knew

https://www.waveshare.com/wiki/2.8inch_DSI_LCD

Need the rotation

Looks like you chain the commands together like:

8:38 PM

I still haven't gotten this screen to rotate damn, I'm on trixie

Damn... it's funny I have no idea how this GUI DSI thing works...

I was expecting I could just "output an image" somehow to the display but it's I think HDMI out and it's only outputting the terminal... so I don't know how I'd output my custom image-based menu.

Still researching, I may have to go back to a full OS install and then boot some kind of Python GUI there if I can't do it from lite.

I'm not sure if I really want to write my own X11 display thing to accomplish this.

8:50 PM

The thing is my menu system isn't even streaming video (until it gets to the camera pass through then it would have to)

It's just pulling pre-made menu images based on the menu state to show

https://forums.raspberrypi.com/viewtopic.php?t=152264

That looks interesting, openbox although I wouldn't use tkinter

8:52 PM

Okay intalling `openbox`

also installing `xinit`

Idk what myapp is will see

8:58 PM

Yoooo there's a little mouse lmao

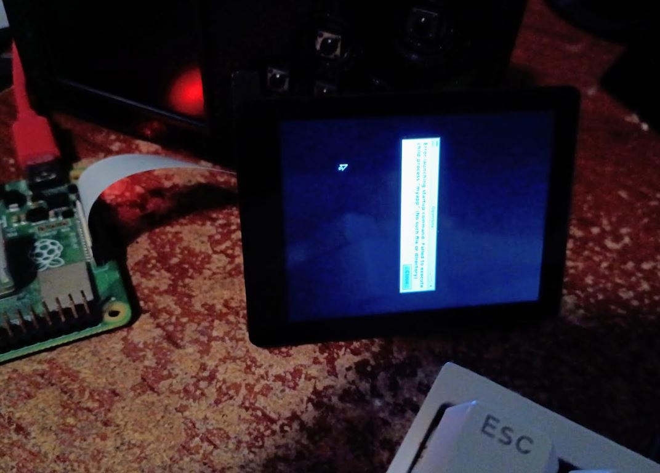
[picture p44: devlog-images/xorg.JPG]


I still don't understand how to control what is shown but this is something.

9:03 PM

It seems I have to use xrandr so installing that via `x11-xserver-utils`

Okay I got it rotated with just `rotate -o left`

The touch is not rotated

Need `xinput`

oohhhhh man's learninnnn

`DISPLAY=:0 xinput`

after it's running but I'm just trying to figure out what input to target

https://askubuntu.com/questions/368317/rotate-touch-input-with-touchscreen-and-or-touchpad

9:12 PM

Still not working but the device name is `10-0014 Goodix Capacitive TouchScreen`

Yeah when I move my thumb up in landscape mode the cursor goes left

9:20 PM

Tried rotating through boot firmare config file no dice

9:32 PM

Alright I got it, there was an error saying "device name shows up multiple times"

I had to use the device ID

So I've got custom window, rotated display and input

I still don't know how to output something specific like a picture

9:58 PM

Okay I think I understand how this works

You need to produce a window bare minimum.

Then the GUI is in that, in my case it's just static images that change based on the menu state but also I can inject the camera frames for the live pass through.

It seems like I can use OpenCV for it which seems overkill but if it works...

10:01 PM

I'm in the zone autozone baby

I did think about what the OLED could show, it could show the settings of the camera or specific profiles

10:20 PM

Install pip

need to pip install cv2, numpy

sudo apt install python3-pip

10:23 PM

alright guess I'll setup a virtual environment, confusing with display vs. actual camera code

python3 -m venv pelicam

source pelicam/bin/activate

pip install opencv-python

Had to add this script type as it thinks it's shell

10:36 PM

deactivate to leave

10:40 PM

Cool we have a display!



I'll get rid of the extra crap but yeah

10:55 PM

Okay so that this point I have a blank menu now



Trying to figure out how to hide the cursor right now

using unclutter

https://superuser.com/questions/442416/can-i-hide-the-mouse-cursor-in-openbox

11:04 PM

This works

https://bbs.archlinux.org/viewtopic.php?id=43947

Although when you click it shows up, so I guess I'll have to do the transparent theme

11:12 PM

REEEEEEEEEE lmao I can't get this cursor to go away, it's mostly away

But when you touch the screen it shows up very briefly and goes away again

Since the menu is not clickable I'm going to have to have a thread that's listening for touch input then pass that on to the menu system

11:49 PM

Alright I'm spent today, I was trying to get clicks to be detected, doesn't seem like it's working

Not sure if that's a touch thing with openbox or what

Also need to verify the framerate of the imshow, I was initially going for 60fps but I could be fine with 30fps

---

### 01/01/2026

8:08 PM

I feel like I'm being bad by not following through with my projects. I was supposed to design the dead space 3 scavenger robot and make it/paint it but I didn't get around to it.

I kind of lost the drive after a while. I will complete it at some point, I'm feeling interest in making this camera instead though even though outside it's winter so everything is brown and dead here in the midwest.

I started buying a bunch of parts, I'm looking at wide angle lenses next to try.

I'm also looking into tuning the camera for the Minolta 50mm F1.7

Did a base design, ordered the sea-green filament

9:18 PM

I guess I didn't have to buy 3 different brands of these adapters oh well.

Also seems like most of the single-digit focal length lenses are fish eye.

So I'm not sure, I don't want that skewing/warping problem.

10:10 PM

I design the cameras inside-out, I start by modeling the parts and then fit them inside a shell.

Of course here I have a design I want in mind but yeah.

This is what happens though when you use off-the-shelf parts.

11:58 PM

I think I have almost all of the parts to build this camera already. I do have to wait for the OLED now that I decided to add.

I'll need to model all the parts and get the other adapters to check their dimensions, make sure they fit.

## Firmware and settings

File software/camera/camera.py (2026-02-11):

# http://github.com/raspberrypi/picamera2/blob/main/examples/mjpeg_server.py

import io
import time
from picamera2 import Picamera2
from picamera2.encoders import JpegEncoder
from picamera2.outputs import FileOutput
from threading import Condition

base_path = "/home/pi/pelicam/src/camera/captured_media/"

class StreamingOutput(io.BufferedIOBase):
  def __init__(self):
    self.frame = None
    self.condition = Condition()

  def write(self, buf):
    with self.condition: 
      self.frame = buf
      self.condition.notify_all()

class Camera:
  def __init__(self):
    self.picam2 = Picamera2()
    self.output = None

    self.photo_config = self.picam2.create_still_configuration(
      main={"size": self.picam2.sensor_resolution, "format":"RGB888"}
    )

    self.video_config = self.picam2.create_video_configuration(
      main={"size": (640, 480), "format":"RGB888"},
    )

  def change_mode(self, mode):
    if mode == "full":
      self.picam2.switch_mode(self.photo_config)
    else:
      self.picam2.switch_mode(self.video_config)

  def take_picture(self):
    img_path = base_path + str(time.time()).split(".")[0] + ".jpg"
    self.change_mode("full")
    self.picam2.capture_file(img_path)
    self.change_mode("stream")

  def start_streaming(self):
    self.picam2.configure(self.video_config)
    self.output = StreamingOutput()
    self.picam2.start_recording(JpegEncoder(), FileOutput(self.output))

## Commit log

2026-01-04 buttons interfaced
2026-01-11 small print
2026-01-14 import existing SketchUp models
    [18650-protected-cell.skp, 5-d-joystick.skp, 5v-1a-charger.skp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]
2026-01-14 modeling progress
    [0.91-inch-OLED-0.skp, 0.91-inch-OLED.skp, 2.8-inch-dsi-display.skp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]
2026-01-14 time to start on body
    [2.8-inch-dsi-display.skp, back-button.skp, hinge.skp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]
2026-01-14 image of modeled parts
    [0.91-inch-OLED-0.skp, 0.91-inch-OLED.skp, 18650-protected-cell.skp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]
2026-01-14 bring in adafruit speaker
    [adafruit-speaker.skp, camera-assembly.skp]
2026-01-16 do it lad
    [camera-assembly.skp]
2026-01-18 it's ugly
    [camera-assembly-0.skp, camera-assembly.skp]
2026-01-18 starting to print display caddy
    [camera-assembly-0.skp, camera-assembly.skp, display-caddy.skp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]
2026-01-18 more modeling progress
    [camera-assembly-0.skp, camera-assembly.skp, display-caddy.skp]
2026-01-18 now time to print
    [back-half-0.skp, back-half.skp, back-half.stl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]
2026-01-19 exploded view
    [camera-assembly.skp]
2026-01-19 update wiring diagram
    [camera-assembly.skp]
2026-01-25 reduce OLED gap
    [back-half.skp, back-half.stl, corrective-piece-oled.skp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]
2026-01-25 add note about 3D printed problems
2026-01-28 add BOM
2026-01-28 no lens
2026-02-04 add note about lens mount adjustment
2026-02-10 add pass through sample
2026-02-12 note about power supply
